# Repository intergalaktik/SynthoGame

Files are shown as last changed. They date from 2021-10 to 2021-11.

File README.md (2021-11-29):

# SynthoGame
RP2040 based Synth

Synthogame RP2040 based FM synthesis synth

### FM synthesis

What is FM synthesis?

FM synthesis is short for frequency modulation synthesis. FM synthesis is a method of generating complex timbres by modulating the frequency of one sound with another. FM was invented by John Chowning at Stanford University in the late 60s, but it didn’t become popular until Yamaha released the DX7 synthesizer based on the technology in 1983. The DX7 sold thousands of units and went on to define the sound of synths in the 1980s. Simply put, FM synthesis uses one signal called, the “modulator” to modulate the pitch of another signal, the “carrier”, that’s in the same or a similar audio range. This creates brand new frequency information in the resulting sound, changing the timbre without the use of filters. For clarity’s sake, "timbre" is the distinctive character of a sound. The timbre of a sound depends upon its frequency content.The frequencies present in a piano sound, for example, are different than those in a guitar sound, even at the same pitch and level. This is what makes them sound different.

Explanation are taken from: 

- https://blog.landr.com/fm-synthesis/
- https://cymatics.fm/blogs/production/fm-synthesis

So check those blogs to learn more!

### Hardware

Synthogame firmware runs on Raspberry Pi RP2040 microcontroller.

Besides RP2040 microcontroller Synthogame contains USB-C connector (power and communication), DAC (Digital Analog Converter), headphone amplifier, LINE OUT, MIDI IN/OUT, addressable RGB LED array, indication leds, buttons, encoder, touch buttons and touch screen.

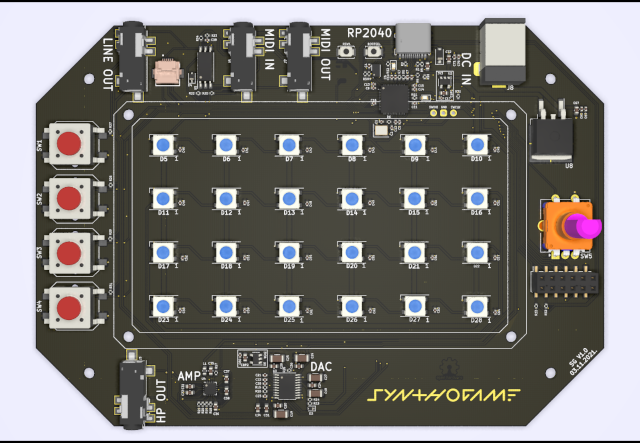
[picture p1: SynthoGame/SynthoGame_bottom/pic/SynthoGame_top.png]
SynthoGame main board - top side


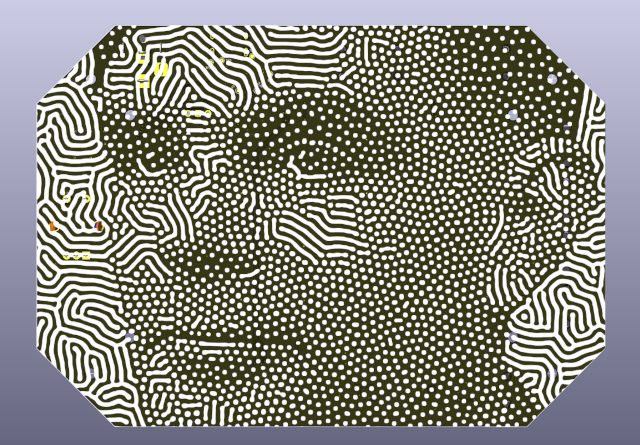
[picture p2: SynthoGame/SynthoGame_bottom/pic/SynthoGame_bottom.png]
SynthoGame main board - bottom side


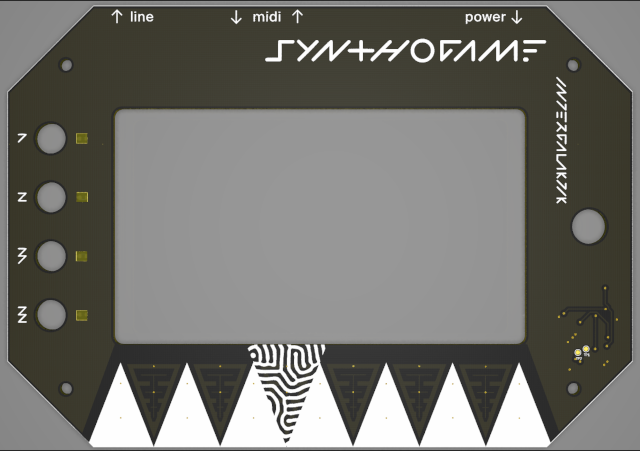
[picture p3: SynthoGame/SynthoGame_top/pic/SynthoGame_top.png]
SynthoGame touch board - top side


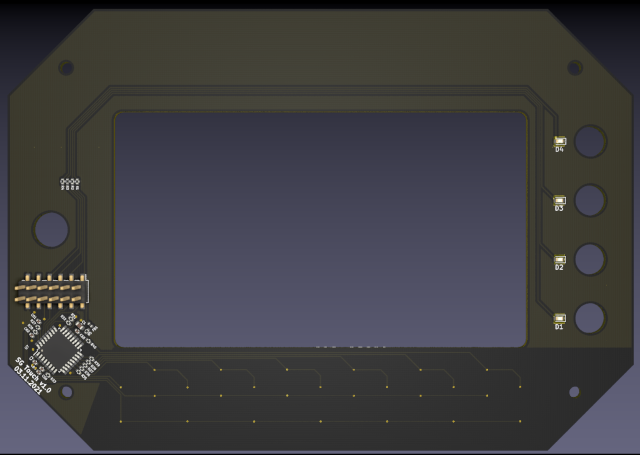
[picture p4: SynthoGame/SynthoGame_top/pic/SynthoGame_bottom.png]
SynthoGame touch board - bottom side


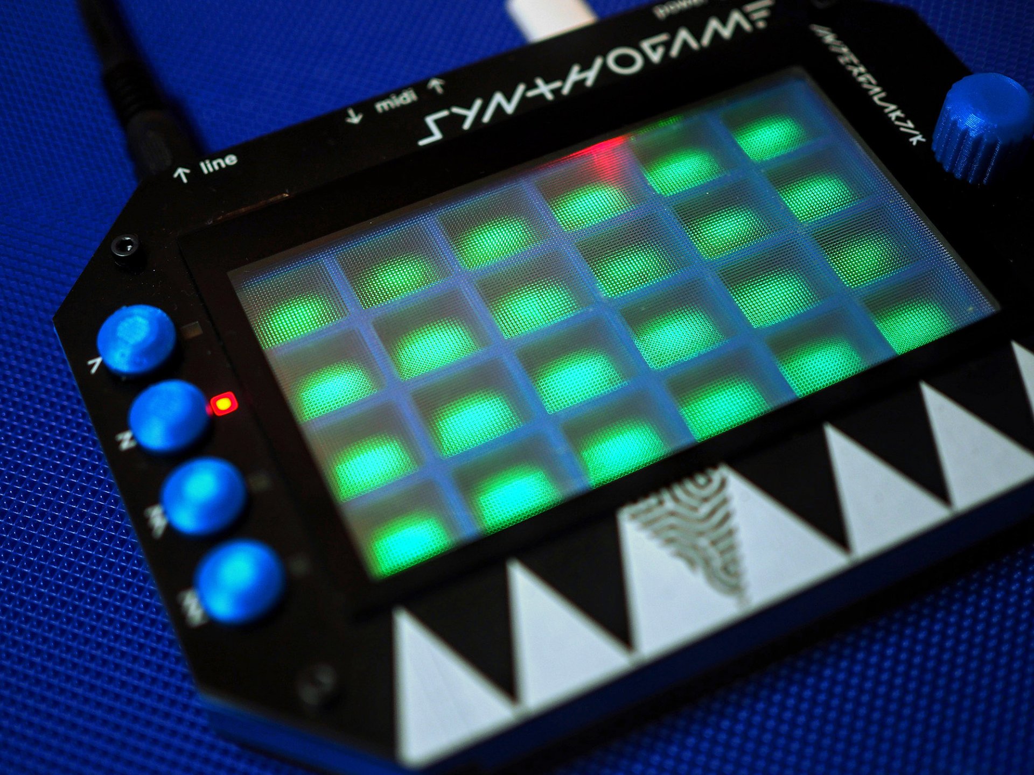
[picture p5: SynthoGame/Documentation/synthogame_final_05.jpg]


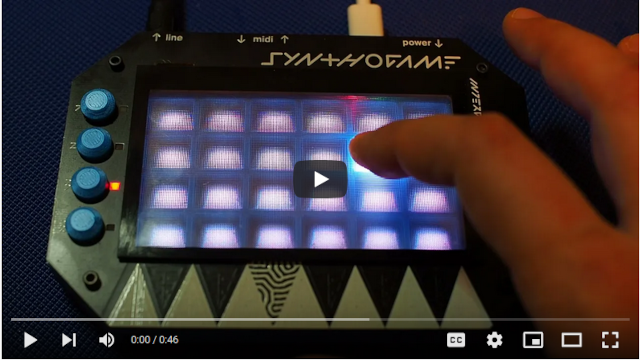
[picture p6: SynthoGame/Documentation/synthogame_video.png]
Watch the video (https://youtu.be/HBAlY6ak0zU)


Design by: Damir Prizmić

[Hyperglitch Ltd](https://hyperglitch.com)

Intergalaktik Ltd

[RP2040 schematics by: Envious Media](https://envious.media)

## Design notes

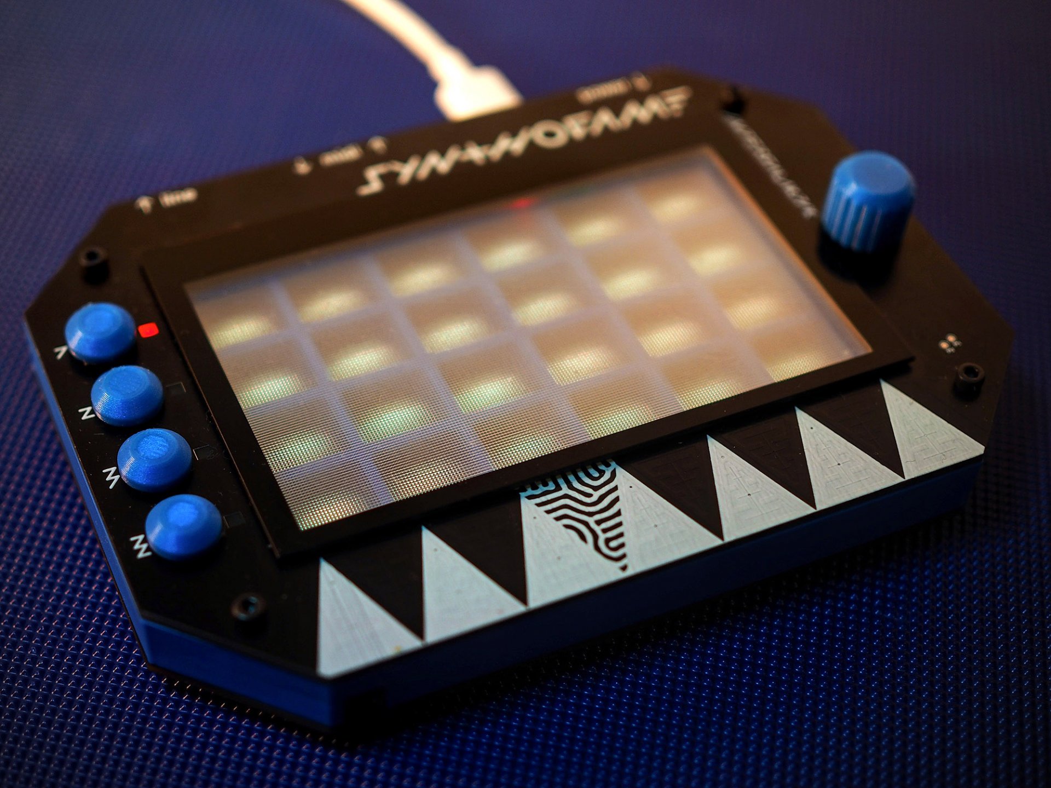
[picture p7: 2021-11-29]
SynthoGame/Documentation/synthogame_final_01.jpg

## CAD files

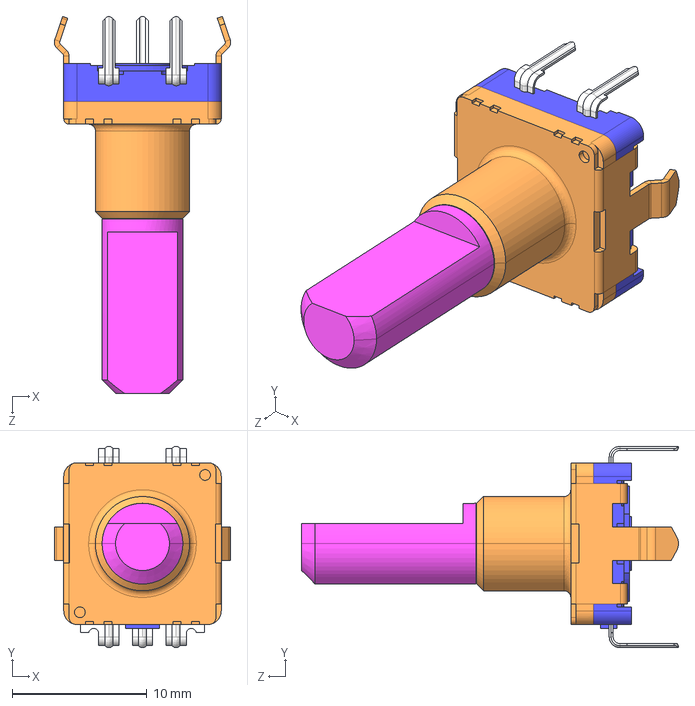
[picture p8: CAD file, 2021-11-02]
SynthoGame/Resources/Encoder/EC11E-nonSW.STEP
13.1 x 15.0 x 28.0 mm

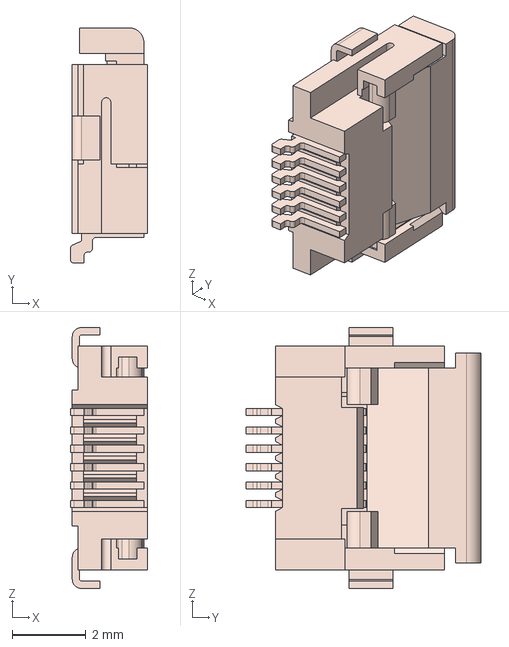
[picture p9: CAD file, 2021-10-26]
SynthoGame/Resources/Hirose-FH12/FH12-6S.step
2.10 x 6.40 x 7.10 mm

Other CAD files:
SynthoGame/Resources/Hirose-FH12/FH12-6S_fixed.step
SynthoGame/Resources/Hirose-FH12/FH12-6S-0.5SH_55_.stp

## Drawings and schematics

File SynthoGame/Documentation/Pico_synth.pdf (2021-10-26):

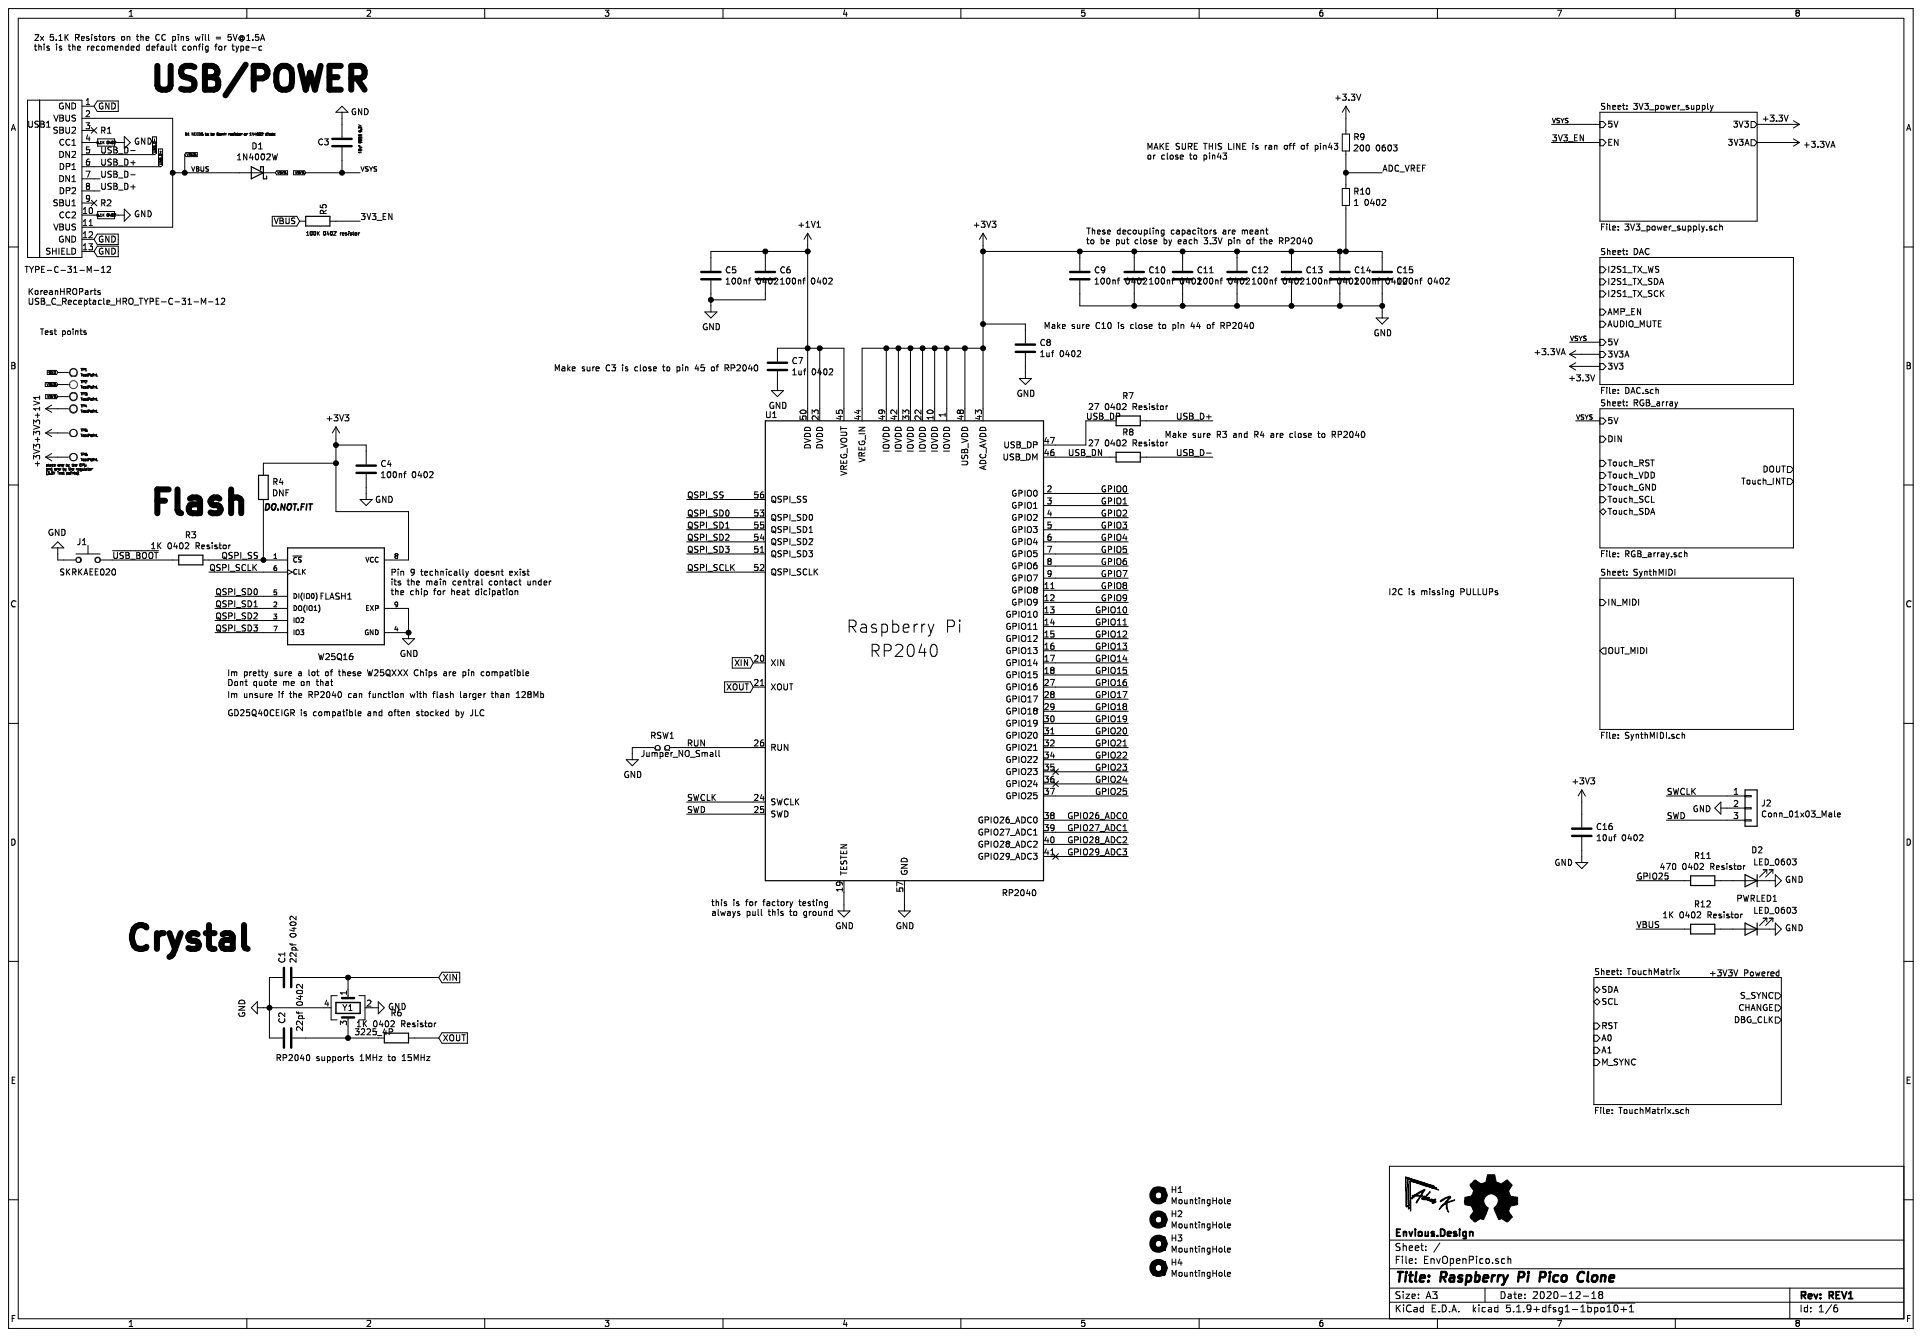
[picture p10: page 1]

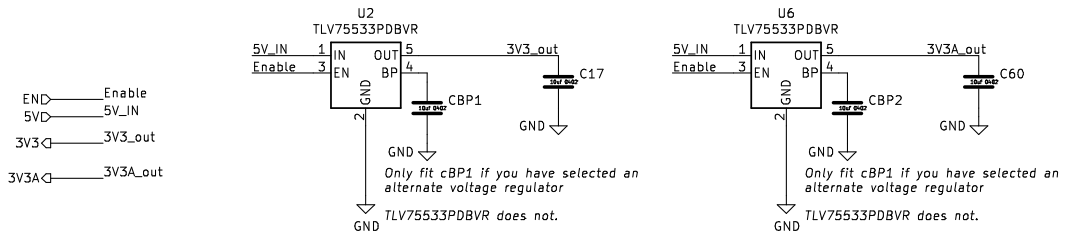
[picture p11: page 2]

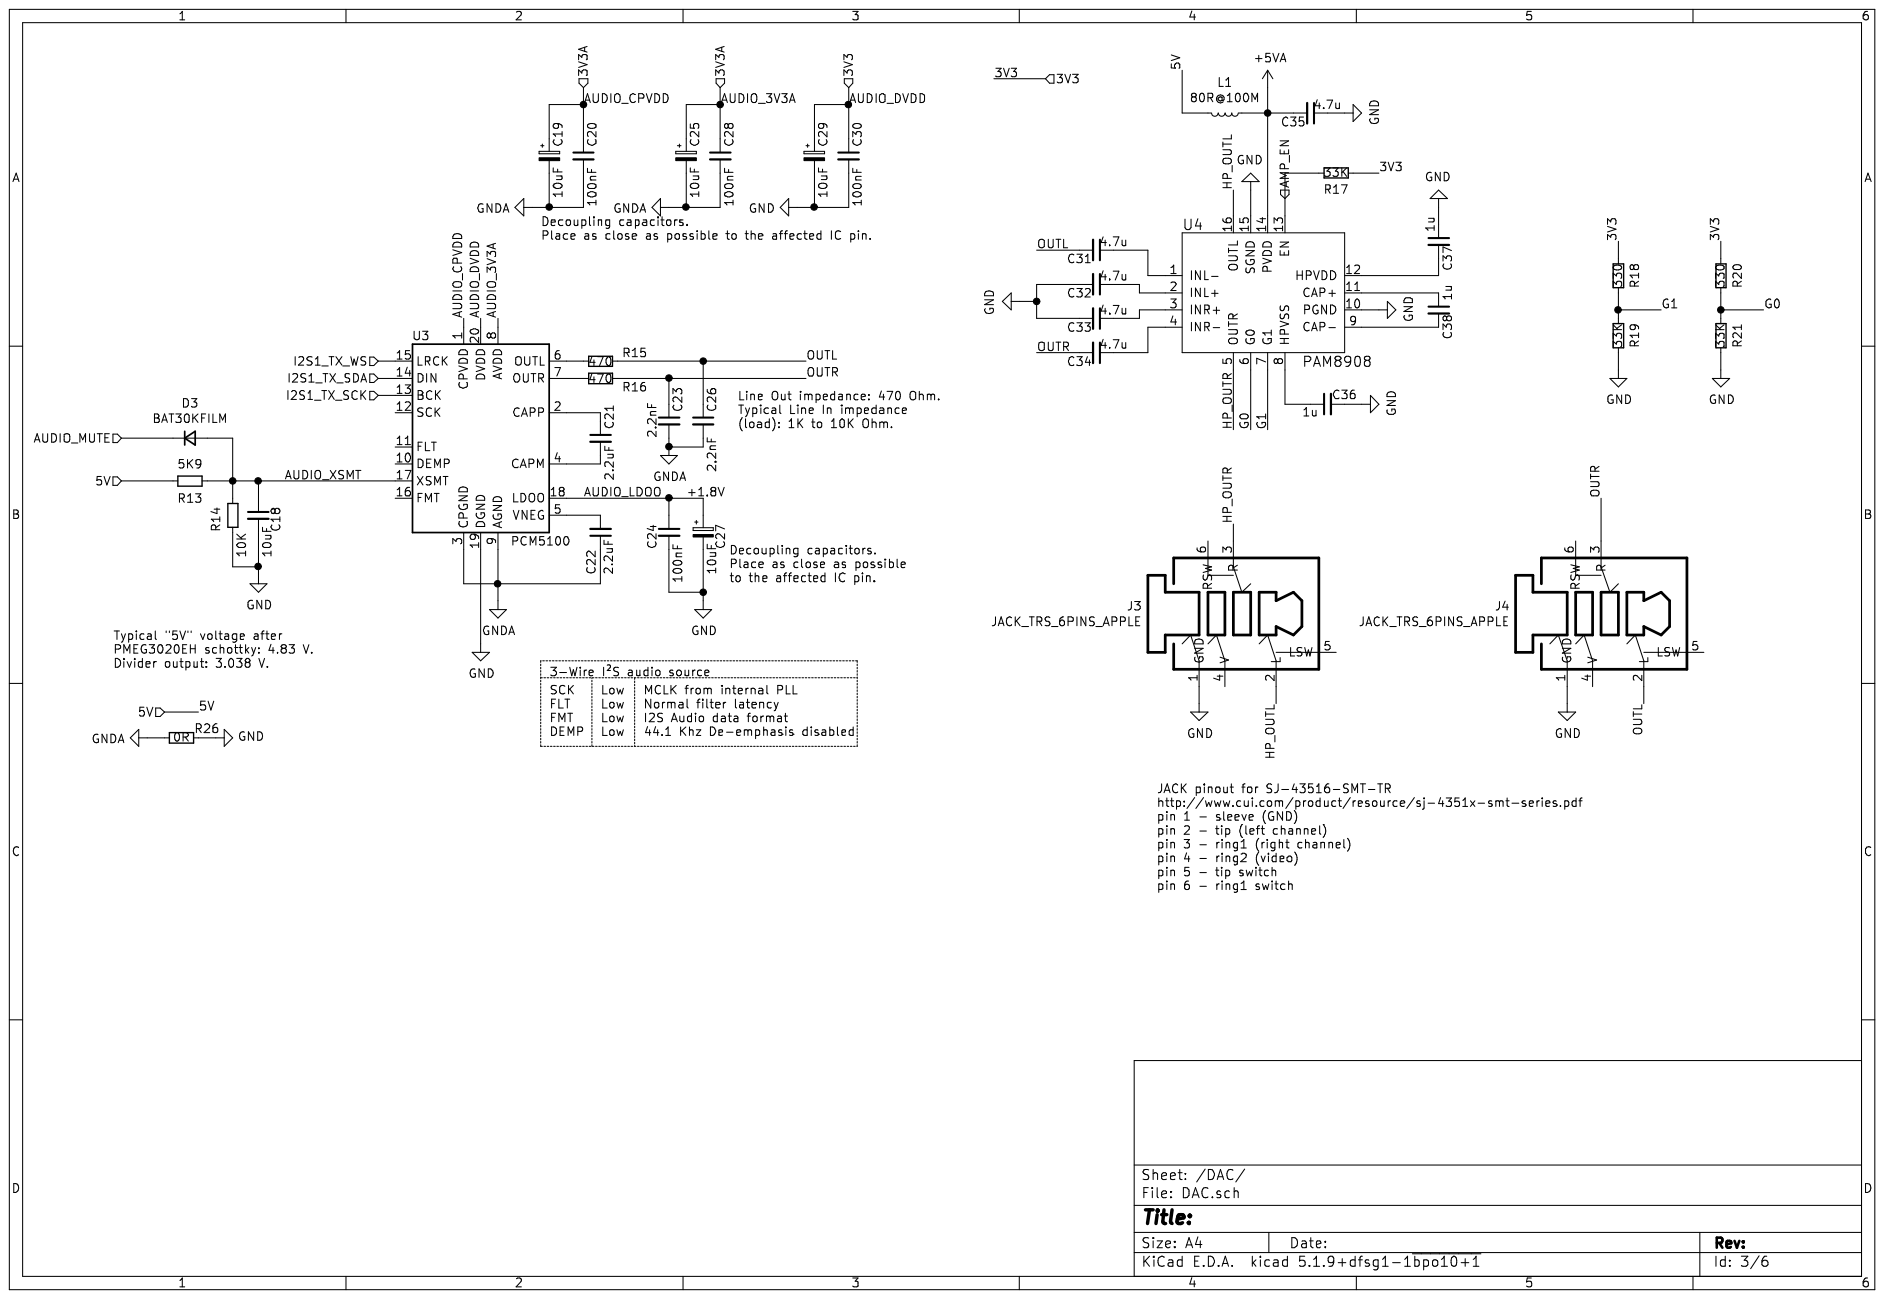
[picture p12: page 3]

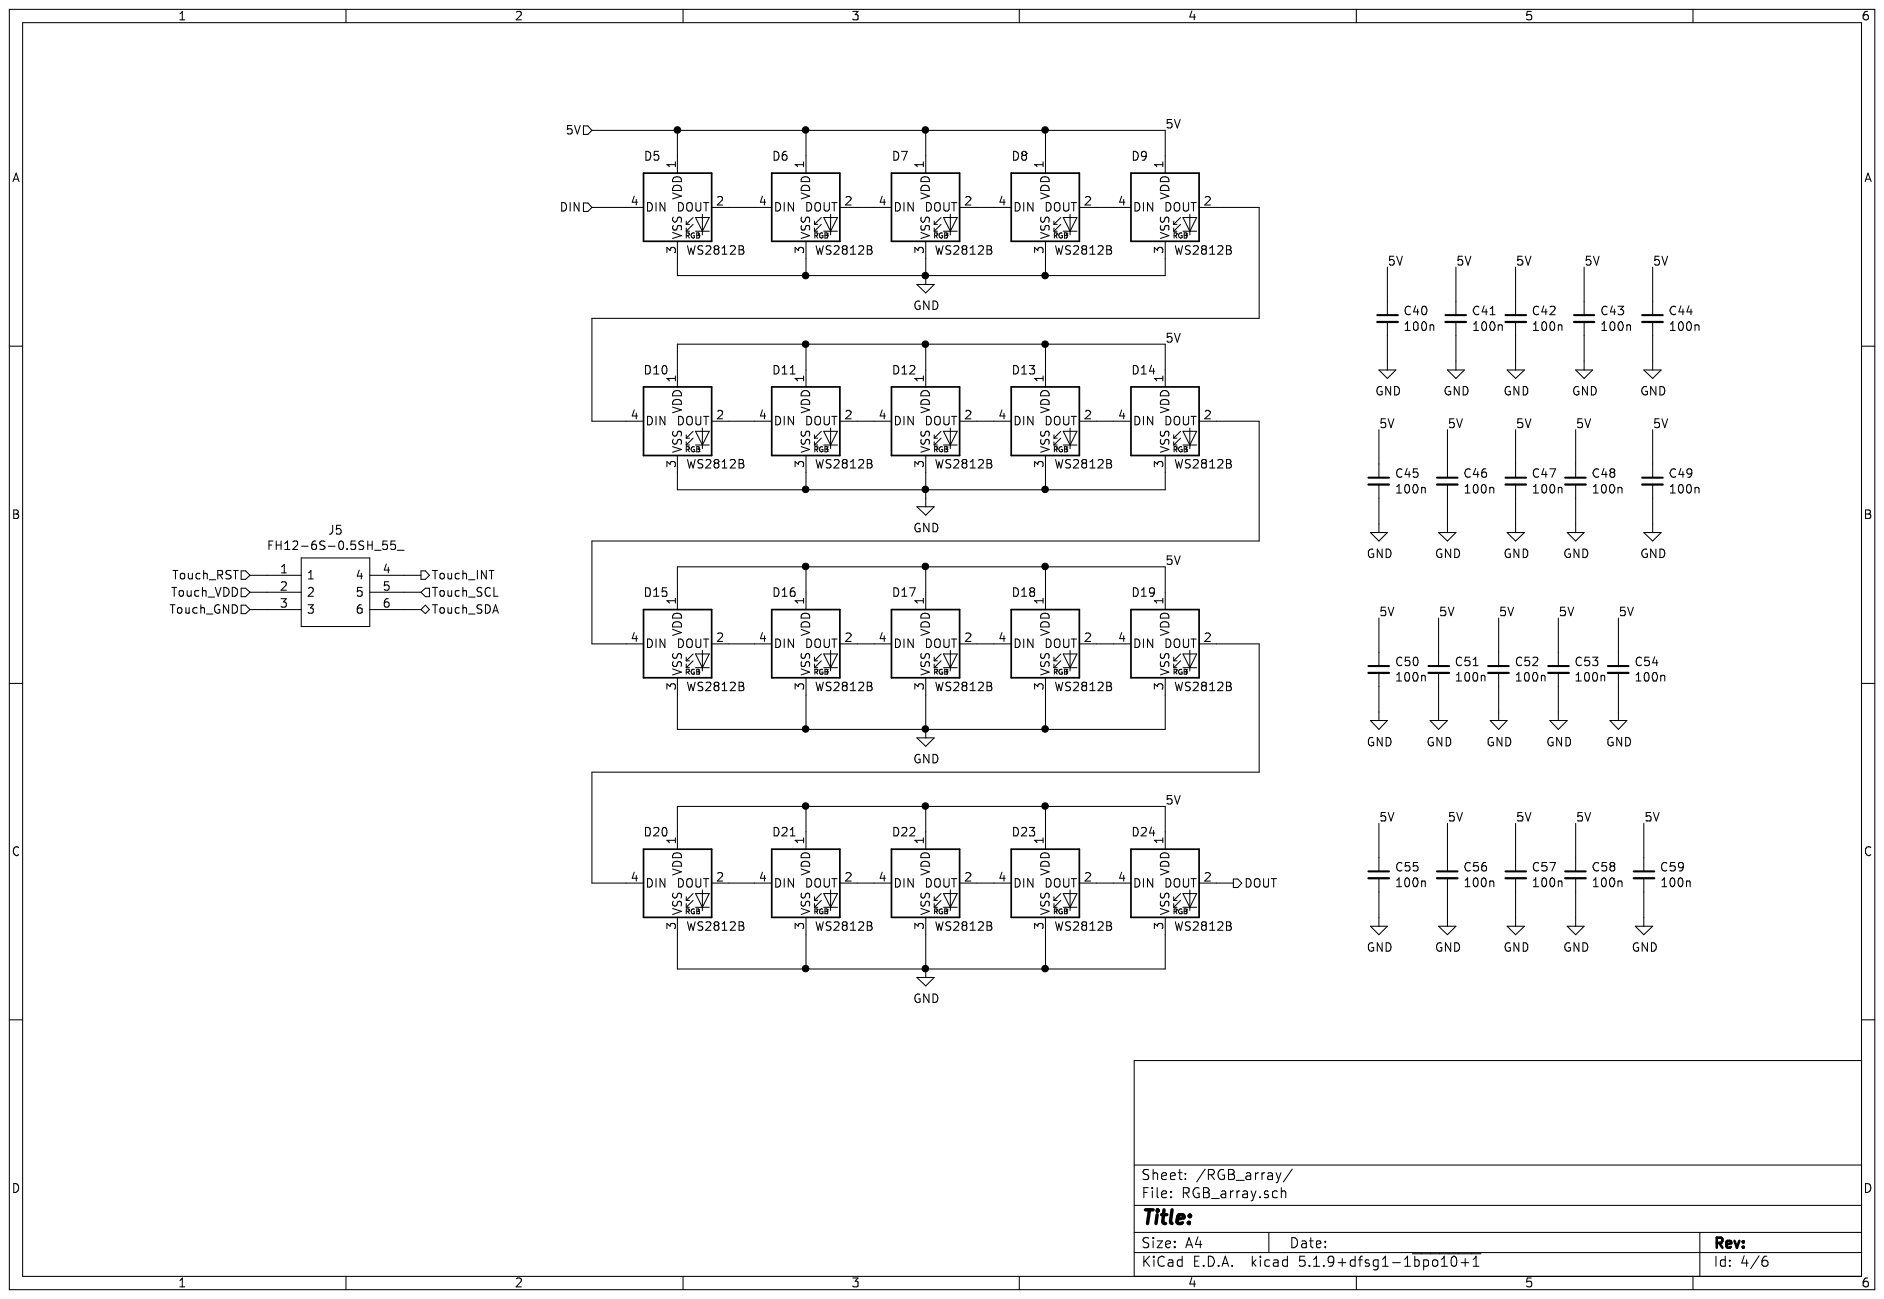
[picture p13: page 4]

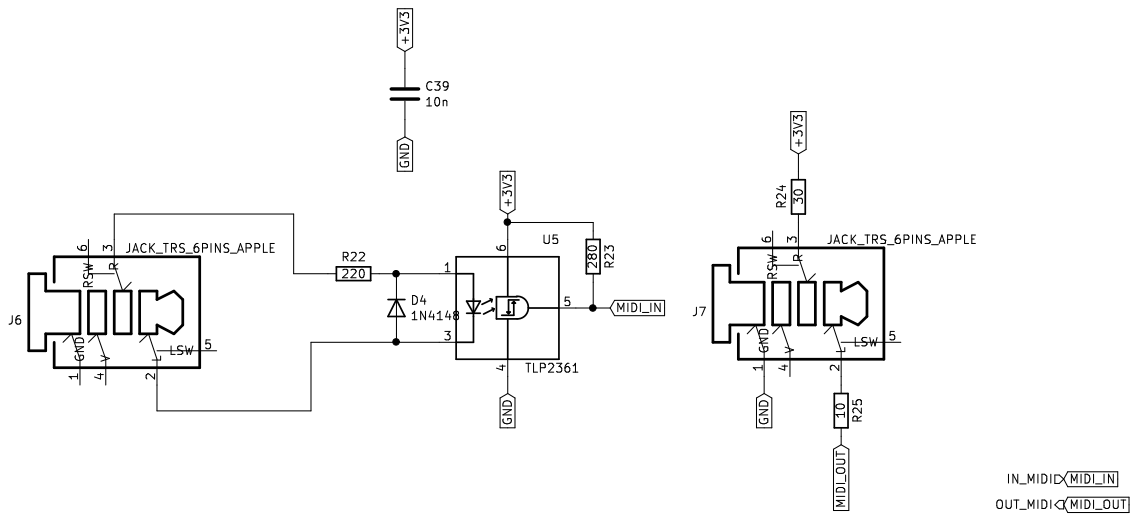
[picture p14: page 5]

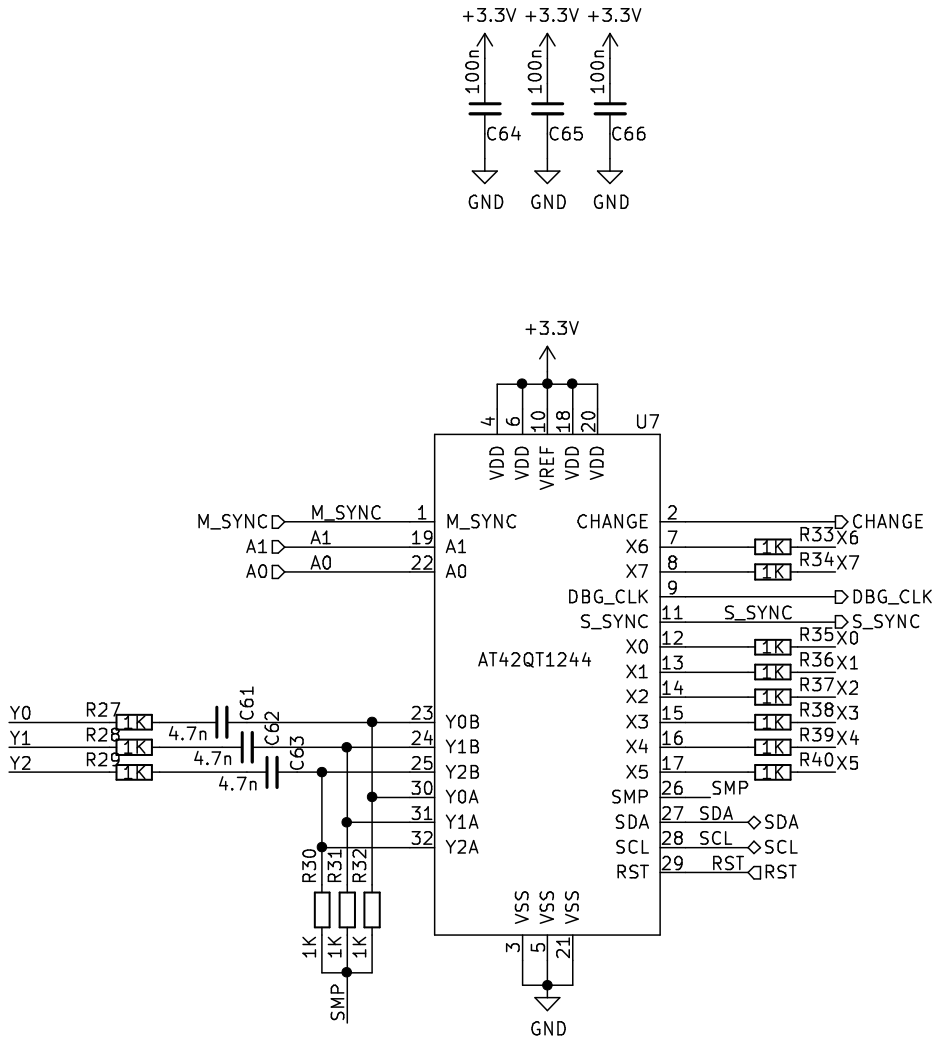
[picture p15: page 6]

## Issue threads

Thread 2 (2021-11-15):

Touch screen connector has wrong pinout

goran-mahovlic, 2021-11-15:
It needs to be mirrored

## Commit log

2021-10-19 Adding DAC
    [3V3_power_supply.sch, DAC.sch, EnvOpenPico.kicad_pcb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]
2021-10-20 Adding audio out, adding pdf schematics
    [DAC.sch, EnvOpenPico.sch]
2021-10-21 Adding parts to pcb
    [3V3_power_supply.sch, DAC.sch, EnvOpenPico.kicad_pcb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]
2021-10-21 Adding LED arrayž
    [3V3_power_supply.sch, DAC.sch, EnvOpenPico.kicad_pcb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]
2021-10-22 Adding touch connector
    [EnvOpenPico.kicad_pcb, EnvOpenPico.sch, FH12-6S-0.5SH_55_.stp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]
2021-10-26 Adding Touch
    [3V3_power_supply.sch, DAC.sch, EnvOpenPico.kicad_pcb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]
2021-10-26 Removing not needed dir
    [3V3_power_supply.sch, DAC.sch, Dip40-RP2040-32A.kicad_pcb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]
2021-10-26 Moving to right directories
    [3V3_power_supply.sch, DAC.sch, RGB_array.sch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]
2021-10-26 Adding power supply
    [SynthoGame.kicad_pcb, SynthoGame.sch]
2021-10-26 Moving components
    [SynthoGame.kicad_pcb]
2021-10-26 Adding touch to top board
    [SynthoGame_top.kicad_pcb]
2021-10-26 Removing touch from bottom board
    [SynthoGame.kicad_pcb, TouchMatrix.sch]
2021-10-26 Adding connector
    [SynthoGame.kicad_pcb, SynthoGame_top.kicad_pcb, SynthoGame_top.sch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]
2021-10-31 add board shape, main component placement
    [RGB_array.sch, SynthoGame.sch]
2021-10-31 define shape for top board
2021-10-31 Routing top
    [SynthoGame_top.kicad_pcb]
2021-10-31 Locking footprint - adding new netlist
    [SynthoGame_top.kicad_pcb]
2021-10-31 connecting I2S - routing
    [3V3_power_supply.sch, DAC.sch, SynthoGame.kicad_pcb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]
2021-10-31 Adding serial resistors to I2S
    [3V3_power_supply.sch, DAC.sch, SynthoGame.kicad_pcb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]
2021-11-01 fix few ERC errors
    [SynthoGame.sch]
2021-11-02 bottom board: adjust connector position
    [SynthoGame.kicad_pcb]
2021-11-02 fix top board wiring, add touch key footprint, adjust connector position
    [SynthoGame_top.kicad_pcb, SynthoGame_top.sch]
2021-11-02 Changing X pinout - connecting 3.3V
    [SynthoGame_top.sch]
2021-11-02 Changing path of USB connector
    [SynthoGame.kicad_pcb]
2021-11-02 Connecting all pins, adding 3D encoder, adding BOM
    [EC11E-nonSW.STEP, SynthoGame.kicad_pcb, SynthoGame.sch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]
2021-11-03 fix mounting hole position
    [SynthoGame_top.kicad_pcb]
2021-11-03 resolve ERC errors, minor tweaks
    [3V3_power_supply.sch, DAC.sch, RGB_array.sch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]
2021-11-03 add graphic overlays
    [SynthoGame.sch, SynthoGame_top.kicad_pcb, SynthoGame_top.sch]
2021-11-03 move touch key symbol/footprint to resources dir
2021-11-03 Improved routing - small visual changes
    [SynthoGame_top.kicad_pcb]
2021-11-03 Adding gerber files
    [SynthoGame-B_Cu.gbl, SynthoGame-B_Mask.gbs, SynthoGame-B_Paste.gbp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]
